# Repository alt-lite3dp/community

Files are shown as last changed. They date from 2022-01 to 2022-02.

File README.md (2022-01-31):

# Lite3DP Community Projects

Welcome to the the community projects, a curated place to host community projects related to the Lite3DP.

Check the following folders in the source:

- [`printer_mods`](./printer_mods)
- [`firmware_configurations`](./firmware_configurations)
- [`slicer_configurations`](./slicer_configurations)

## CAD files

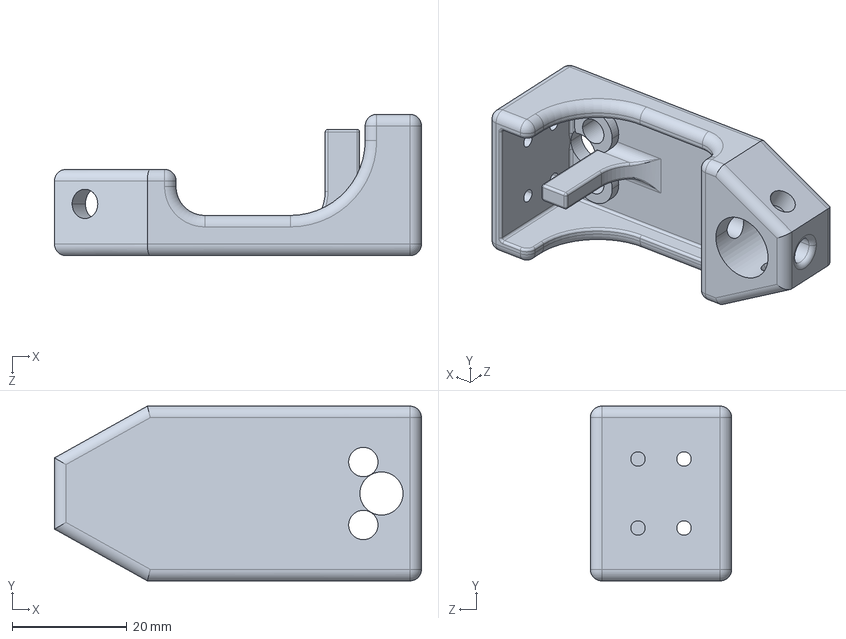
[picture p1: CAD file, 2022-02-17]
printer_mods/joeman94/Carriage_mk1_5/CAD/Carriage mk1_5.STEP
63.8 x 30.4 x 24.6 mm

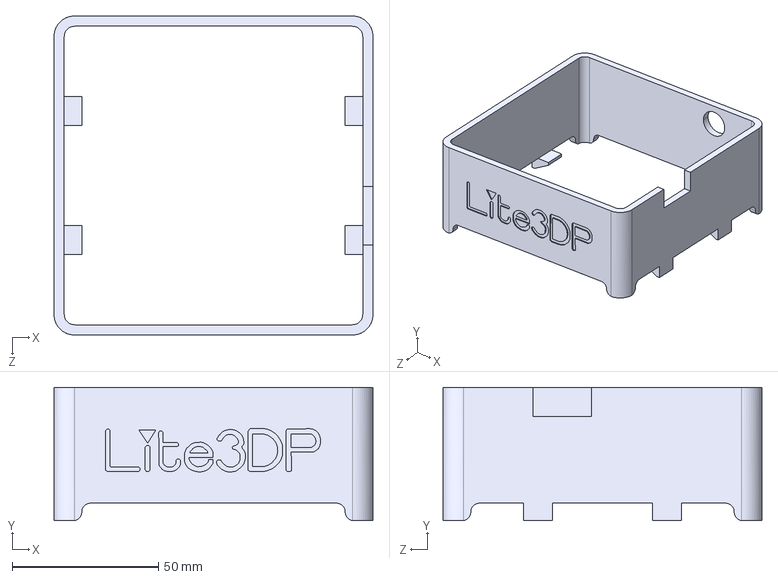
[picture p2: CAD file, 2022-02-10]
printer_mods/joeman94/Modified_Base/CAD/Modified_Base.STEP
109.0 x 45.6 x 109.0 mm

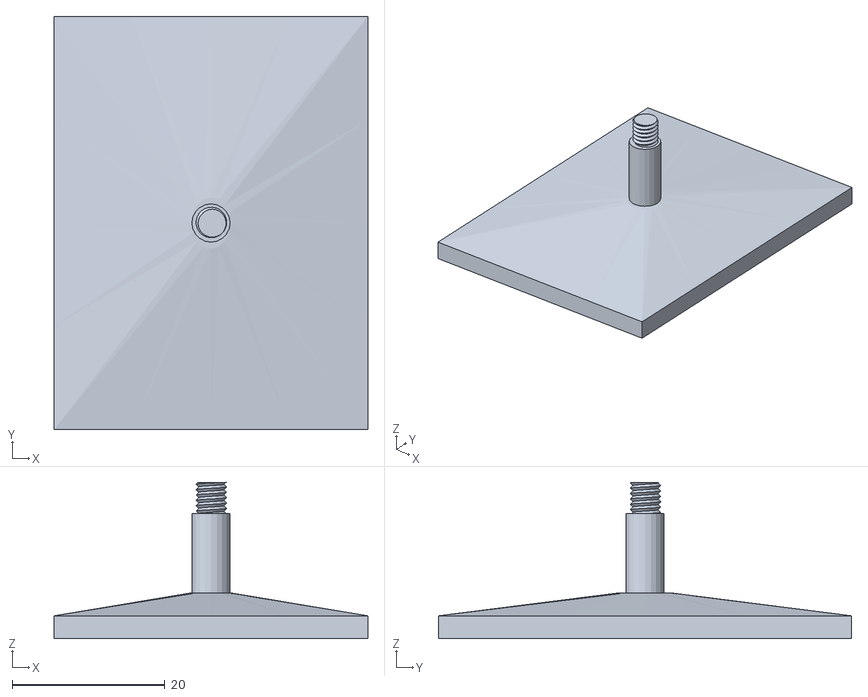
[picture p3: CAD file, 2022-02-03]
printer_mods/JoLamMaker/FDM_MagneticBuildPlate/STL/MagneticBuildPlatform_R1.stl
41.0 x 54.0 x 20.5

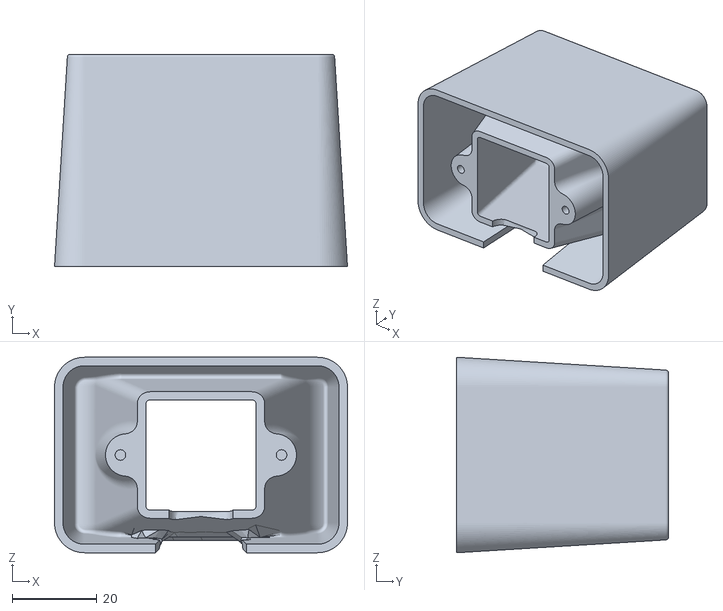
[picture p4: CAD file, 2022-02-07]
printer_mods/JoLamMaker/UV_OverFocusPatch/STL/50mmHeight_Base_r2.stl
69.1 x 50.0 x 46.1

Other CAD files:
printer_mods/joeman94/Carriage_mk1_5/CAD/Carriage mk1_5.SLDPRT
printer_mods/joeman94/Carriage_mk1_5/CAD/Carriage_mk1_5.SLDPRT
printer_mods/joeman94/Carriage_mk1_5/CAD/Carriage_mk1_5.STEP
printer_mods/joeman94/Carriage_mk1_5/STL/Carriage mk1_5.STL
printer_mods/joeman94/Carriage_mk1_5/STL/Carriage_mk1_5.STL
printer_mods/joeman94/Modified_Base/CAD/Modified_Base.SLDPRT
printer_mods/joeman94/Modified_Base/STL/Modified_Base.STL

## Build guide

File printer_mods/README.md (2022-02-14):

# Mods

Printer modifications for the Lite3DP-S1 3D SLA DLP Printer.

**Remember to update this README when uploading new mod!**

## Table structure

Update the following table with the information about your mod:

- Your name
- A link to your sub-folder
- A short description of your mod

like so:

`| Creator | [Mod title](link) | Description |`

---

| Creator | Mod Title | Description |
| --- | --- | --- |
| joeman94 | [Modified Base](./joeman94/Modified_Base/) | A base that allows the printer to simply slide in and out for easy maintenance. Uses the original top cover. |
| | [Carriage 1.5](./joeman94/Carriage_mk1_5/) | A reverse engineered carriage that allows for use of M3 brass insets
| JoLamMaker | [FDM Magnetic Build Plate](./JoLamMaker/FDM_MagneticBuildPlate/) | A spare build platform printable on 3D printers with threads for the stock steel ball. |
| | [UV Over-focused Patch](./JoLamMaker/UV_OverFocusPatch/) | Adds 15 mm of extra separation for the UV light beam to diffuse |

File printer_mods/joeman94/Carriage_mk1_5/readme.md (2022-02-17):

master
This is a a modified version of the original carriage to allow use of M3x5x4 brass insets instead of threading directly into the plastic.

I have finally had the chance to print this for myself and test it and all of the issues I encountered have been resolved,but if you try it yourself, please feel free to
correct my work or let me know so I can.

DO NOTE. The size of the z stop tab is slightly different from the original, here is what a recommend doing to prevent a crash. Once you have the head mounted, turn on
the printer and allow the "Prepare" function to run WITHOUT the bed attached. Once it is at the bottom, you can use the up and down keys to trim the z level of the 
bed a few milimeters. Use the up key and trim it as far up as it will go. This is a setting that is saved in the printer firmware. Then press ok. Now, put your 
bed on and redo the prepare function. Use the up and down keys to adjust the bed as you see fit. I like to have a bit of friction with a piece of printer paper over the
screen like on an FDM printer, but I may be completly wrong about that. Works for me tho. 

This process should keep you from cracking the carriage and breaking your screen.

Anyway, heres a pic of it on my printer. 

master

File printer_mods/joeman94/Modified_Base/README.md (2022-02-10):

A base that allows the printer to simply slide in and out for easy maintenance.

Allows for use of original top cover.





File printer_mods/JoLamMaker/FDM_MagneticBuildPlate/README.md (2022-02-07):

## Problem

Lite3DP-S1 comes with only one print platform and we need to do leveling every print.. What makes the issue worse, I play with it with different test print recently.

As a result, It is time wasting because next print have to wait until I recover resin, remove print and clean the build platform.

## Solution

Due to the small size of the printer, it is not difficult to make build platform with FDM 3D printer.

Crastinblack already made a good start, but I prefer to make it more complete by print out the M4 thread and install Round Screw Ball (10mm diameter, M4 bore) specified by lite3DP.

Original model by Crastinblack: <https://www.thingiverse.com/thing:5030681>

## Bill Of Material

1. Printout of [MagneticBuildPlatform_R1.stl](./STL/MagneticBuildPlatform_R1.stl) in this folder.
2. Round Screw Ball (10mm diameter, M4 bore)

## Usage

Just print many! (MagneticBuildPlatform_R1.stl)
Then we can print immediately after the previous one finish.
Printing can run parallel when recovering resin, removing print and cleaning the build platform.

1. Place the model like this:
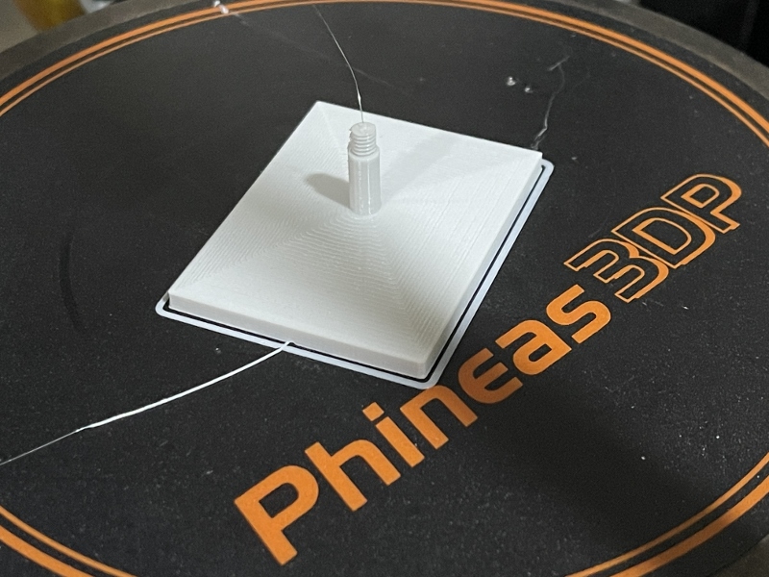
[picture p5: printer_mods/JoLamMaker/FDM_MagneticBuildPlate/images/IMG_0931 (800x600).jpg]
Print Position
   
2. Screw in Steel Ball:
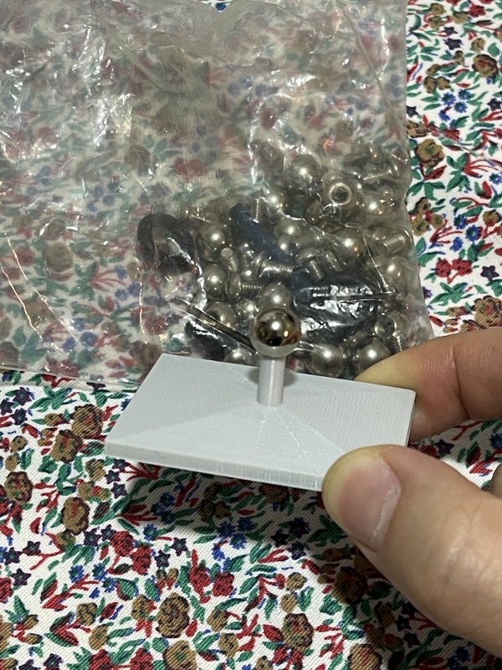
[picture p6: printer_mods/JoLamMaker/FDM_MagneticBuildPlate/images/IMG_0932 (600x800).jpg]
Screw in the ball
   
3. Use it as-is the origilan aliminium build plate
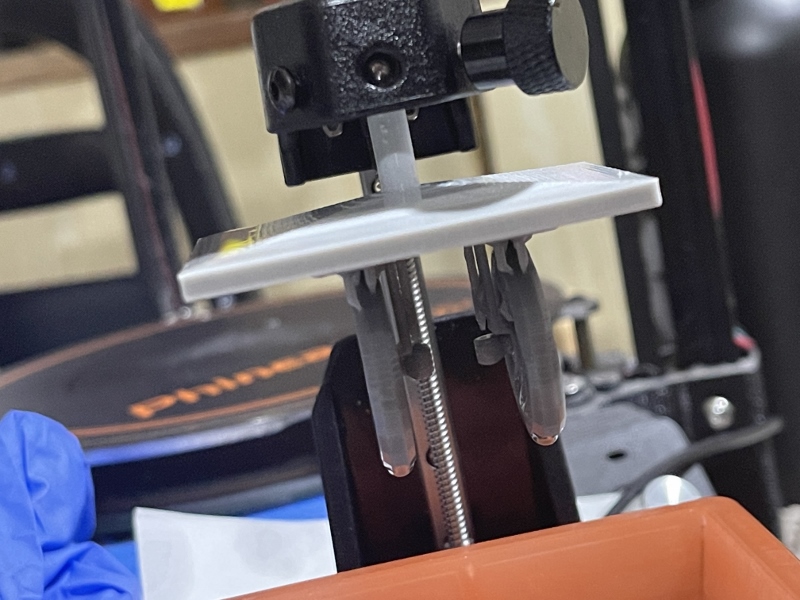
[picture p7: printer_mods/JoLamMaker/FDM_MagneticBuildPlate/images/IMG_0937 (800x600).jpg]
Attached Magnetically
   
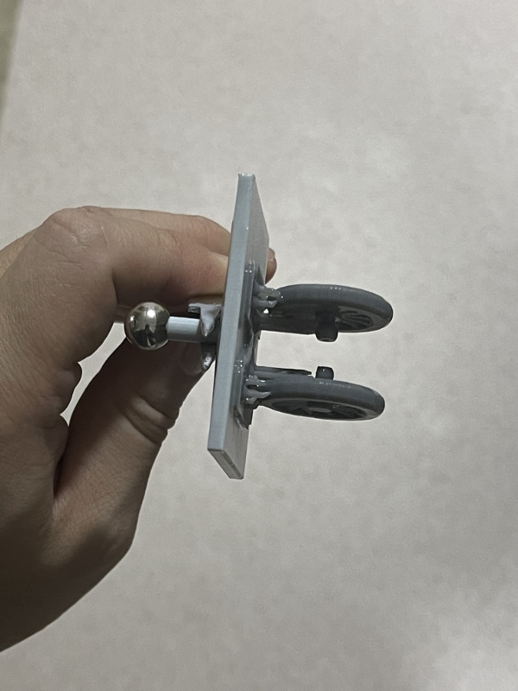
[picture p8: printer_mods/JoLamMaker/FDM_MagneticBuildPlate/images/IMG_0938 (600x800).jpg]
Print nicely


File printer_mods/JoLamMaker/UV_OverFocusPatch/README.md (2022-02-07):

## Problem

I acquired my kit from Mouser Electronic but it solidify everything at the middle even though I set the exposure time to 3 seconds only. This make the printer simply unusable.

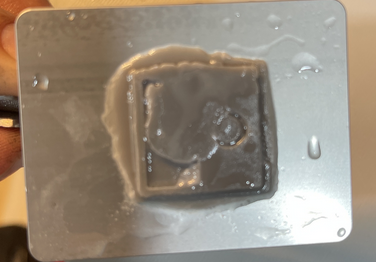
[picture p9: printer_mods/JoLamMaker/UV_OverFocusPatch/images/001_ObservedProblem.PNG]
ObservedProblem


## Root cause

After investigation, the root cause is the beam angle of the ultraviolet LED is too narrow. That makes the center session of print surface receive high intensity of ultraviolet light that able to penetrate the mask.

## Solution

My final solution is simply add 15 mm of extra separation for the light beam to diffuse. Some M3 Male Female Hex Brass Spacer would do the job easily.
Since the original base part no-longer fit after the modification, I modify the file to fit the modified printer so that it does not leak out ultraviolet light.
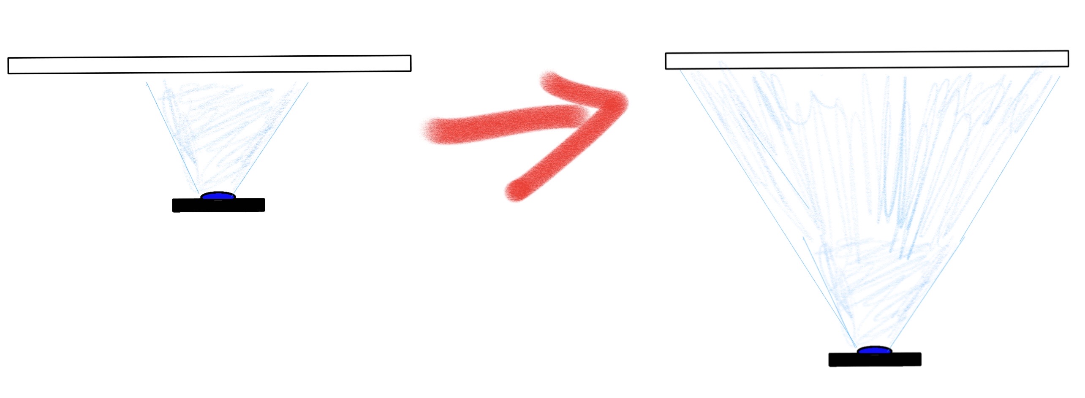
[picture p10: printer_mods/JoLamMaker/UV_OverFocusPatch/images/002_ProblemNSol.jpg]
ProblemNSol


## Preferred tools

1. FDM 3D printer
2. Black colored fliament
3. M3 screw tap

## Bill of material

1. 6 pieces of [15 mm M3 Male Female Hex Brass Spacer] (<https://hk.element14.com/ettinger/05-13-153/spacer-m3x15-ni/dp/1466869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|pcrid|432655398157|pkw||pmt||slid||product|1466869|pgrid|106281172011|ptaid|pla-899072975402|&CMP=KNC-GOO-SHOPPING-1466869>)
2. 1 print out of [50mmHeight_Base_r2.stl](./STL/50mmHeight_Base_r2.stl).

## Usage

1. Add the extra height to the printer by 15 mm M3 Male Female Hex Brass Spacer
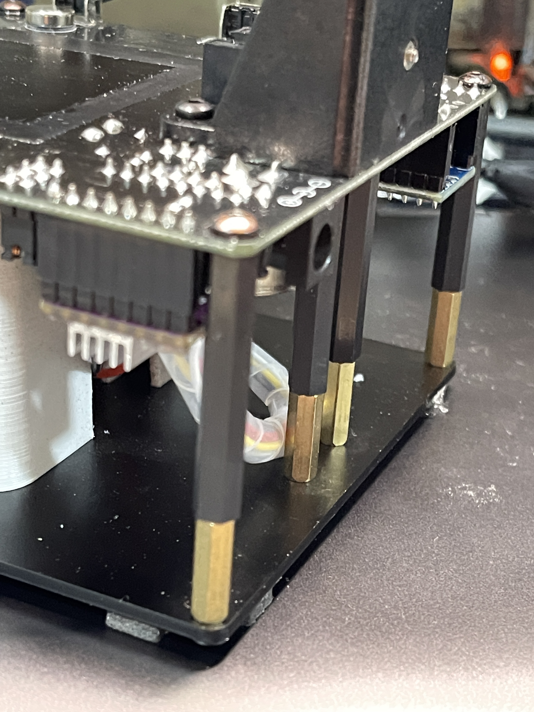
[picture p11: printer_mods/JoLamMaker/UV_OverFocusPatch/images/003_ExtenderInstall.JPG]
ExtraHeight
   
2. If "50mmHeight_Base_r2.stl" is not printed out by black material, paint it in black color. This would avoid many problems caused by internal reflection of UV light.
3. Use M3 screw trap to
4. Install "50mmHeight_Base_r2.stl" as-is the original one.
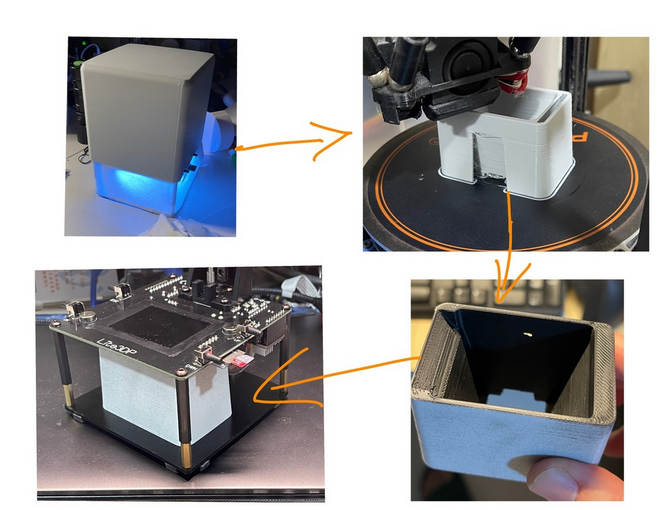
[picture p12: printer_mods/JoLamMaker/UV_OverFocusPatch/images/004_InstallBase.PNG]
Finalize


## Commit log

2022-02-03 Add Magnetic Build Platform (#1)
    [MagneticBuildPlatform_R1.stl]
2022-02-07 Add UV_OverFocusPatch; Update FDM_MagneticBuildPlate (#2)
    * Rename FDM_MagneticBuildPlate/README.md to printer_mods/JoLamMaker/FDM_MagneticBuildPlateREADME.md
    * Rename printer_mods/JoLamMaker/FDM_MagneticBuildPlateREADME.md to printer_mods/JoLamMaker/FDM_MagneticBuildPlate/README.md
    [50mmHeight_Base_r2.stl]
2022-02-07 Refactored Mods Section; Cleaned up READMEs (#3)
    [50mmHeight_Base_r2.stl, MagneticBuildPlatform_R1.stl]
2022-02-07 Add funding options for overall Project
    Individuals are free to list their contribution platforms such as Patreon, GitHub, and so for their mods. Please do!!
    This funding in this commit is for funding the overall costs and maintenance of Discord, Reddit, GitHub, CAD, and so on.
2022-02-10 Add Modified Base by joeman94 (#4)
    [Modified Base.SLDPRT, Modified Base.STEP, Modified Base.STL]
2022-02-10 Remove carriage_v2 until it is ready
2022-02-10 Remove spaces in joeman94; Refact joeman94 directories and files
    [Modified_Base.SLDPRT, Modified_Base.STEP, Modified_Base.STL]
2022-02-14 Add mod Carriage MK1.5 for Heatset Inserts (#5)
    * Add files via upload
    * Add files via upload
    * Create readme.md
    * Create readme.md
    * Delete Modified Base.SLDPRT
    * Delete Modified Base.STEP
    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
    [Carriage_mk1_5.SLDPRT, Carriage_mk1_5.STEP, Carriage_mk1_5.STL]
2022-02-17 Carriage 1.5 Revision. (#6)
    [Carriage mk1_5.SLDPRT, Carriage mk1_5.STEP, Carriage mk1_5.STL]
